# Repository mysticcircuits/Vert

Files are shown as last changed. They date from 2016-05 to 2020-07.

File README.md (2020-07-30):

# Vert
files for the Vert Eurorack module by Mystic Circuits.

This module comes with an open source licence, CC-BY-SA 3.0.  Go ahead and read the licence page for more details. This means that there are no commercial restrictions on this module.  Please be reasonable in your interpretation of this rule.  I fully support people building their own circuit boards and even trading amongst their friends for them.  However organizing group buys for these PCBs or selling the PCBs on your own will compete directly with my own products, since I sell PCBs on my website and also provide the build documentation and support.  In short - don't be a shmuck about it or else I will stop open sourcing my designs.

Also note that this module is made to function with my "Universal Front Plate" PCB which is hosted in another branch.  It can make the schematic a bit tricky to read sometimes but I did my best to annotate things.  There *might* be some inconsistencies between the pin naming convention for this schematic and the one on the "UFP" schematic because this was the first circuit that I build to work with the UFP and they both went through several revisions together.

For a description of the licence in simple terms please visit https://creativecommons.org/licenses/by-sa/3.0/

*************************************************************************************BUILD INSTRUCTIONS

Here is a link to the instructions.  Please look them over before you attempt to build a Vert and make sure that it is within your skill level.  The Vert is an intermediate build and involves SMD soldering.  I would definitely not attempt to build it as your first project.

https://drive.google.com/file/d/0B1jw1Qp2qZVJNUZ4QTZxX2lhblk/view?usp=sharing

Here is a link to the mouser cart.  Please note that it does not include several components and is also designed to build a VERT with all white LEDs.  Also be aware that I have noticed different behavior between different 555 timer IC models, the model included in the cart is the one that I use because it is stable.

http://www.mouser.com/ProjectManager/ProjectDetail.aspx?AccessID=2263e5f92d

There are two sources for the hardware, unfortunately you can not buy all of what you need from either place:

For the jacks go to either Thonk or Modular Addict.  You need 11 of the the "erthenvar" aka PJ301BM jacks.  Make sure to get nuts along with them, you might have to buy them separately.  Knurled or hex are both fine it's up to you.

https://www.thonk.co.uk/shop/3-5mm-jacks/

https://modularaddict.com/parts/jacks/pj301bm-jacks

You can also buy the vertical PCB mount alpha pots from Thonk/ Modularaddict or Small Bear.  Its way cheaper than buying them from Mouser

1M LINEAR POT x1

100K LINEAR POT x2

https://www.thonk.co.uk/shop/alpha-9mm-pots/

https://modularaddict.com/parts/potentiometers-1/9mm-potentiometers

http://smallbear-electronics.mybigcommerce.com/alpha-single-gang-9mm-right-angle-pc-mount/

Here are the links for the Small Bear parts.  You can buy SPDT switches from a variety of places but I highly suggest buying the short bat toggles listed below.  The switches go in between the pots and so if the bats are too long they will interfere with your ability to turn the knobs comfortably.  I haven't personally tried the Tayda toggle switches but see no reason that they wouldn't work.  If you try them out please let me know how it goes so I can confirm whether or not they are a good choice.

http://smallbear-electronics.mybigcommerce.com/spdt-on-on-0218b/

https://www.taydaelectronics.com/electromechanical/switches-key-pad/toggle-switch/mini-toggle-switch-1m-series-spdt-on-on-short-lever.html

I also buy my purple knobs from Small Bear but any knobs that fit a smooth pot shaft will do.  If you want to use knobs for knurled or D-pot shafts obviously you just have to find the corresponding shaft to replace mine.  I like these pots because they are thin, the painted indicator is inlayed so it wont rub off, and the knurl feels good on the finger.

http://smallbear-electronics.mybigcommerce.com/knurled-silver-center-colors/

https://www.thonk.co.uk/shop/knobs-davies-1900h-clone-metal/

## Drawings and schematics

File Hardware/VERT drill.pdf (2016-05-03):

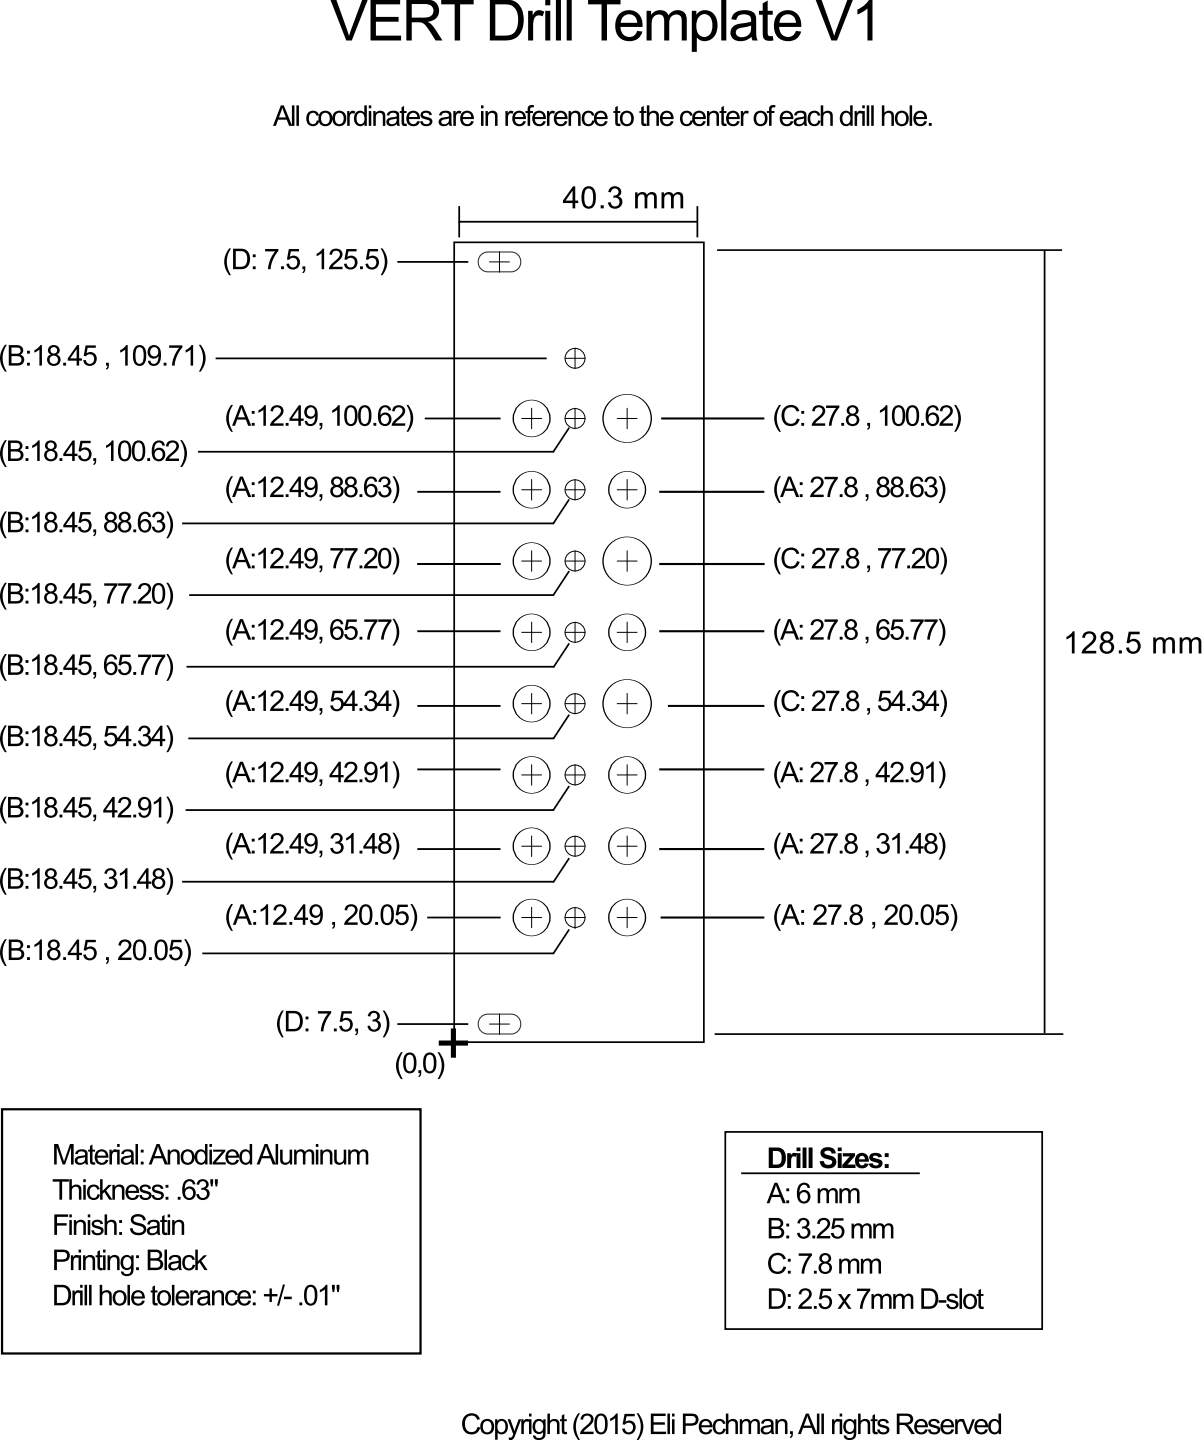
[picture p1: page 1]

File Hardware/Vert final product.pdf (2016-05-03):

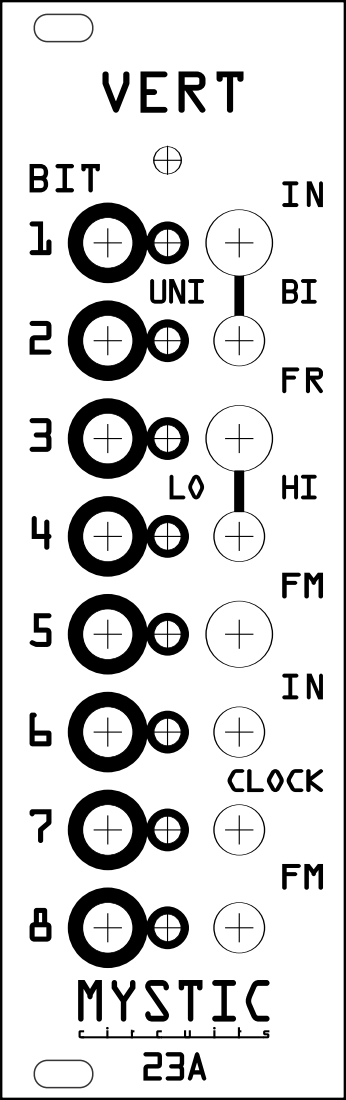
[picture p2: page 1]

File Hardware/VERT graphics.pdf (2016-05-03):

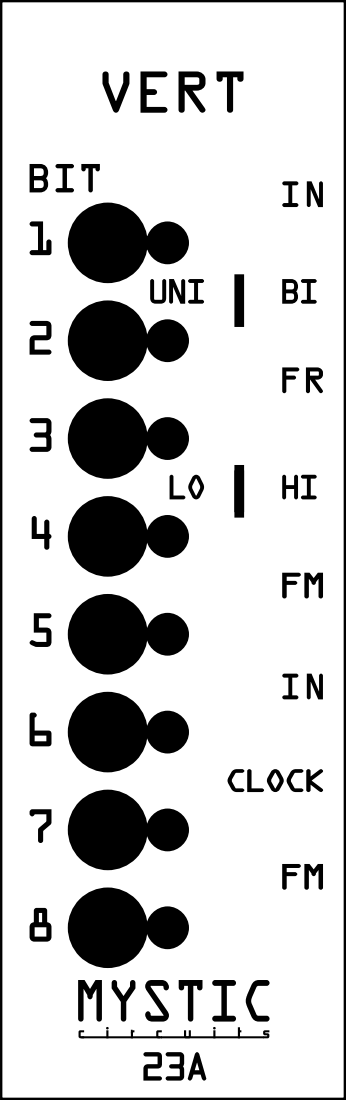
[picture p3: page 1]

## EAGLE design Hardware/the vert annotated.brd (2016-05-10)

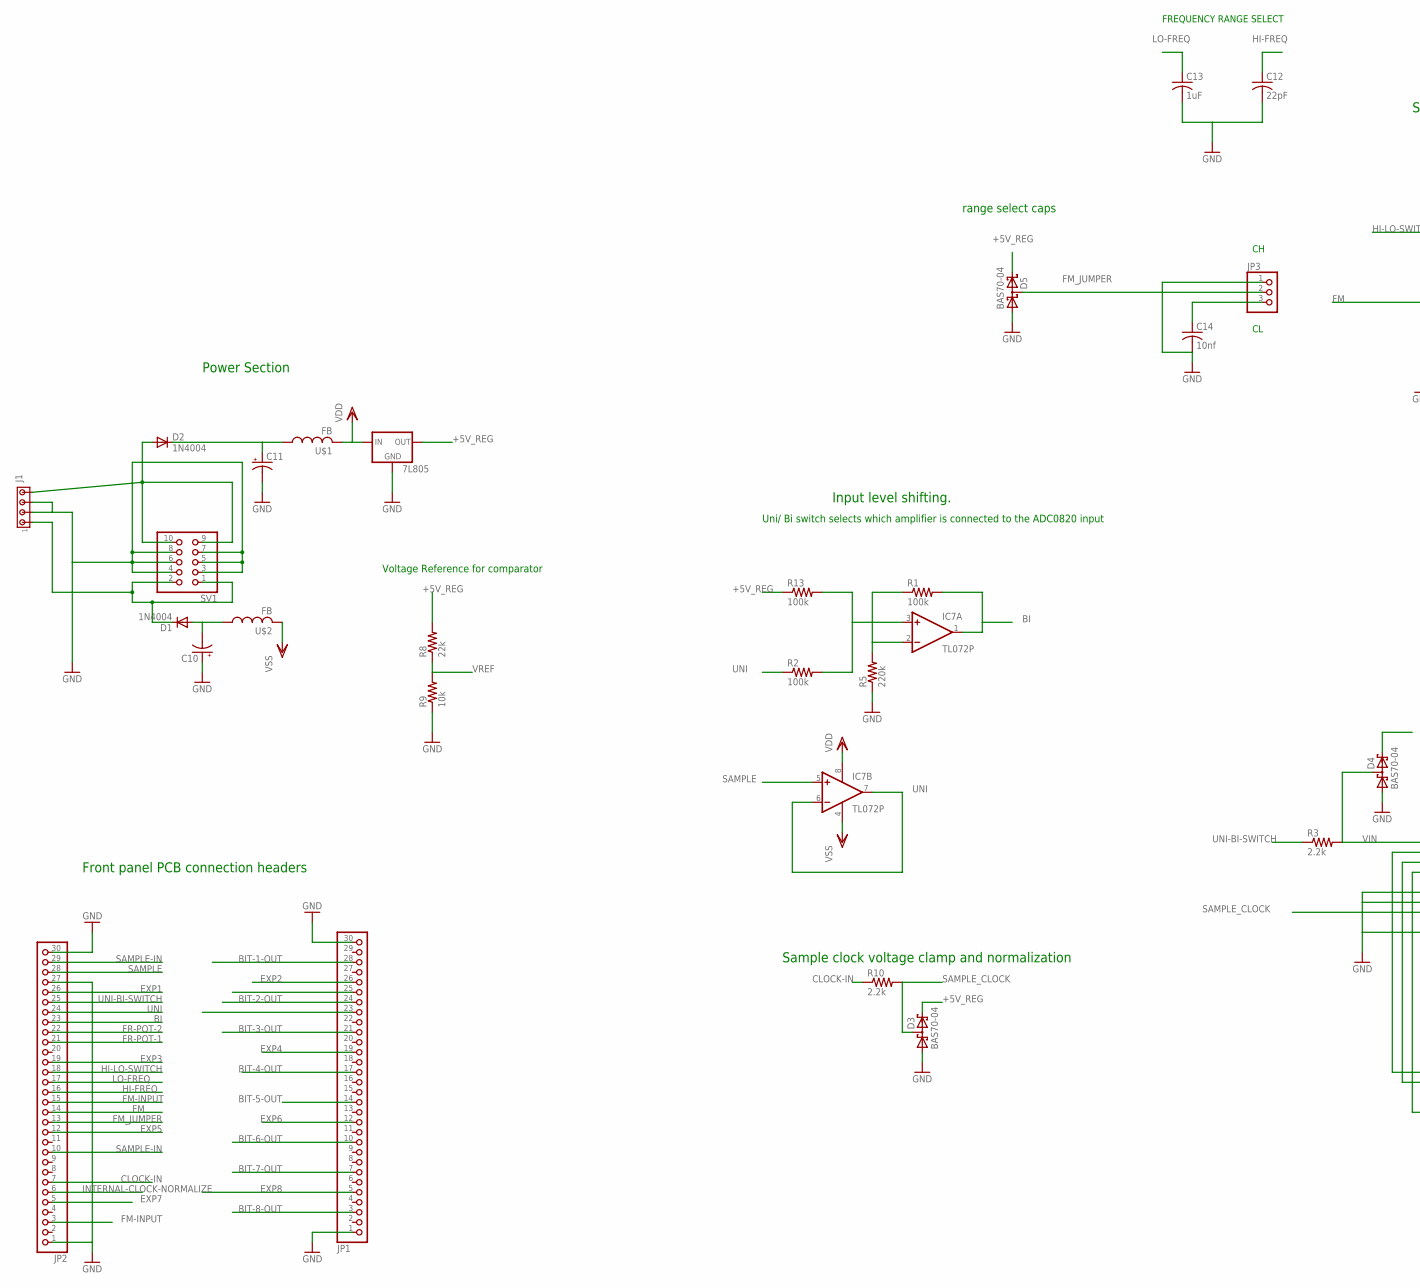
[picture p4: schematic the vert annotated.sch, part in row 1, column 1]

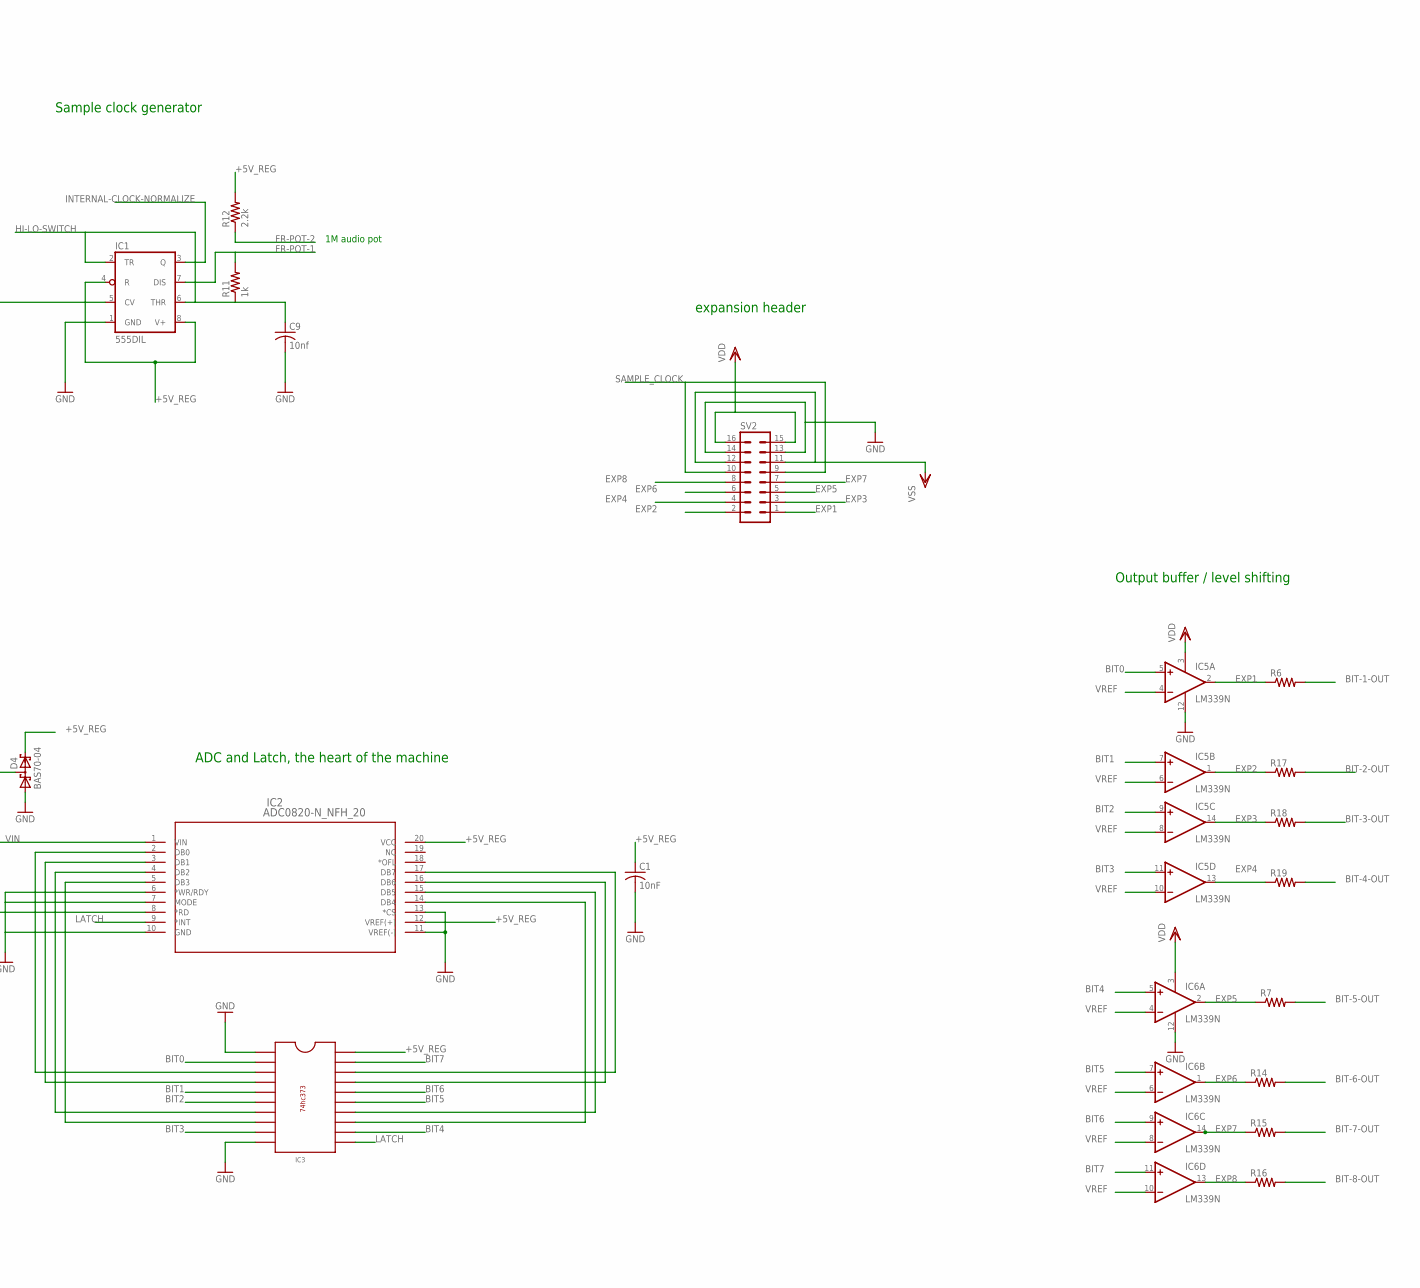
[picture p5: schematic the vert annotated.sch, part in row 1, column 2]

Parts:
7L805: 78LXX
C1: 10nF; C1206
C9, C14: 10nf; C1206
C10, C11: CPOL-USE5-5; E5-5
C12: 22pF; C1206
C13: 1uF; C1206
D1, D2: 1N4004; DO41-10
D3, D4, D5: BAS70-04; SOT23
IC1: 555DIL; DIL08
IC2: ADC0820-N_NFH_20; NFH20
IC3: 74HC373; DIL20
IC5, IC6: LM339N; DIL14
IC7: TL072P; DIL08
J1: MTA04-156; 1X4MTA
JP1, JP2: PINHD-1X30; 1X30
JP3: PINHD-1X3; 1X03
R1, R2, R13: 100k; R1206
R3, R10, R12: 2.2k; R1206
R5: 220k; R1206
R6, R7, R14, R15, R16, R17, R18, R19: R-US_R1206; R1206
R8: 22k; R1206
R9: 10k; R1206
R11: 1k; R1206
SV1: PINHD-2X5; 2X05
SV2: MA08-2
U$1, U$2: FB

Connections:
+5V_REG: 7L805.OUT, C1.1, D3.2 (C2), D4.2 (C2), D5.2 (C2), IC1.4 (R), IC1.8 (V+), IC2.12 (VREF(+)), IC2.20 (VCC), IC3.20, R8.2, R12.2, R13.1
BI: IC7.1 (OUT), JP2.23, R1.2
BIT0: IC3.2, IC5.5 (+IN)
BIT1: IC3.5, IC5.7 (+IN)
BIT2: IC3.6, IC5.9 (+IN)
BIT3: IC3.9, IC5.11 (+IN)
BIT4: IC3.12, IC6.5 (+IN)
BIT5: IC3.15, IC6.7 (+IN)
BIT6: IC3.16, IC6.9 (+IN)
BIT7: IC3.19, IC6.11 (+IN)
BIT-1-OUT: JP1.28, R6.2
BIT-2-OUT: JP1.24, R17.2
BIT-3-OUT: JP1.21, R18.2
BIT-4-OUT: JP1.17, R19.2
BIT-5-OUT: JP1.14, R7.2
BIT-6-OUT: JP1.10, R14.2
BIT-7-OUT: JP1.7, R15.2
BIT-8-OUT: JP1.3, R16.2
CLOCK-IN: JP2.7, R10.1
EXP1: IC5.2 (OUT), JP2.26, R6.1, SV2.1
EXP2: IC5.1 (OUT), JP1.26, R17.1, SV2.2
EXP3: IC5.14 (OUT), JP2.19, R18.1, SV2.3
EXP4: IC5.13 (OUT), JP1.19, R19.1, SV2.4
EXP5: IC6.2 (OUT), JP2.12, R7.1, SV2.5
EXP6: IC6.1 (OUT), JP1.12, R14.1, SV2.6
EXP7: IC6.14 (OUT), JP2.5, R15.1, SV2.7
EXP8: IC6.13 (OUT), JP1.5, R16.1, SV2.8
FM: IC1.5 (CV), JP2.14
FM-INPUT: JP2.3, JP2.15
FM_JUMPER: D5.3 (C1A2), JP2.13, JP3.2
FR-POT-1: IC1.7 (DIS), JP2.21, R11.2
FR-POT-2: JP2.22, R12.1
GND: 7L805.GND, C1.2, C9.2, C10.+, C11.-, C12.2, C13.2, C14.2, D3.1 (A1), D4.1 (A1), D5.1 (A1), IC1.1 (GND), IC2.6 (*WR/RDY), IC2.7 (MODE), IC2.10 (GND), IC2.11 (VREF(-)), IC2.13 (*CS), IC3.1, IC3.10, IC5.12 (GND), IC6.12 (GND), J1.2, J1.3, JP1.1, JP1.30, JP2.1, JP2.27, JP2.30, JP3.1, R5.1, R9.1, SV1.3, SV1.4, SV1.5, SV1.6, SV1.7, SV1.8, SV2.13, SV2.14
HI-FREQ: C12.1, JP2.16
HI-LO-SWITCH: C9.1, IC1.2 (TR), IC1.6 (THR), JP2.18, R11.1
INTERNAL-CLOCK-NORMALIZE: IC1.3 (Q), JP2.6
LATCH: IC2.9 (*INT), IC3.11
LO-FREQ: C13.1, JP2.17
unnamed: D2.A, J1.4, SV1.9, SV1.10
unnamed: C14.1, JP3.3
unnamed: IC7.2 (-IN), R1.1, R5.2
unnamed: D1.C, J1.1, SV1.1, SV1.2
unnamed: C11.+, D2.C, U$1.P$1 (1)
unnamed: IC2.2 (DB0), IC3.3
unnamed: C10.-, D1.A, U$2.P$1 (1)
unnamed: IC7.3 (+IN), R2.2, R13.2
unnamed: IC2.3 (DB1), IC3.4
unnamed: IC2.4 (DB2), IC3.7
unnamed: IC2.5 (DB3), IC3.8
unnamed: IC2.17 (DB7), IC3.18
unnamed: IC2.16 (DB6), IC3.17
unnamed: IC2.15 (DB5), IC3.14
unnamed: IC2.14 (DB4), IC3.13
R-NC-2: JP1.25
R-SW-2: JP1.23
SAMPLE: IC7.5 (+IN), JP2.28
SAMPLE-IN: JP2.10, JP2.29
SAMPLE_CLOCK: D3.3 (C1A2), IC2.8 (*RD), R10.2, SV2.9, SV2.10
UNI: IC7.6 (-IN), IC7.7 (OUT), JP2.24, R2.1
UNI-BI-SWITCH: JP2.25, R3.1
VDD: 7L805.IN, IC5.3 (V+), IC6.3 (V+), IC7.8 (V+), SV2.15, SV2.16, U$1.P$2 (2)
VIN: D4.3 (C1A2), IC2.1 (VIN), R3.2
VREF: IC5.4 (-IN), IC5.6 (-IN), IC5.8 (-IN), IC5.10 (-IN), IC6.4 (-IN), IC6.6 (-IN), IC6.8 (-IN), IC6.10 (-IN), R8.1, R9.2
VSS: IC7.4 (V-), SV2.11, SV2.12, U$2.P$2 (2)

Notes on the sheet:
1M audio pot
range select caps
Output buffer / level shifting
ADC and Latch, the heart of the machine
expansion header
Sample clock generator
Sample clock voltage clamp and normalization
Input level shifting.
Uni/ Bi switch selects which amplifier is connected to the ADC0820 input
Voltage Reference for comparator
Power Section
Front panel PCB connection headers
FREQUENCY RANGE SELECT

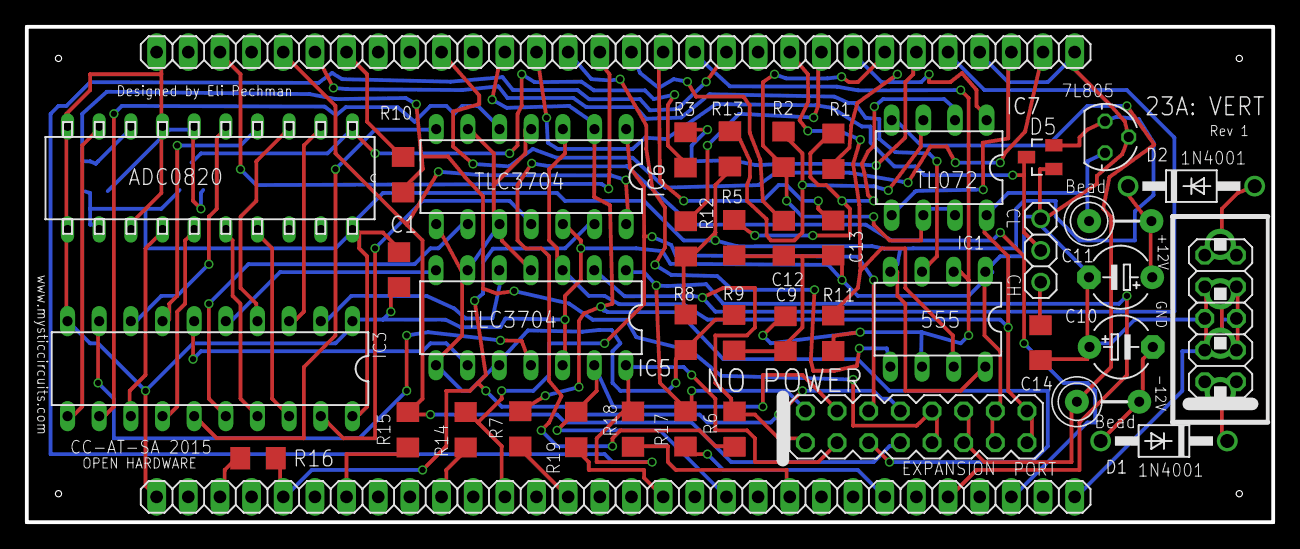
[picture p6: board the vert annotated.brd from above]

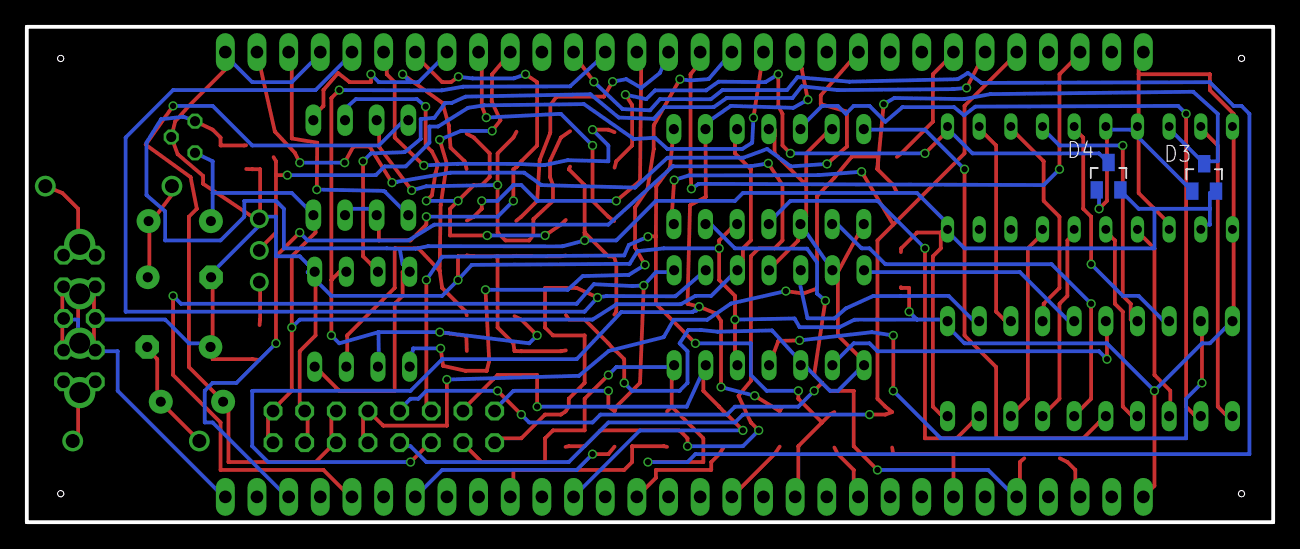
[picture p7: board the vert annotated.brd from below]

Board: 2 copper layers, 100.0 x 39.7 mm, 45 parts (2 on the bottom side), 62 nets.
